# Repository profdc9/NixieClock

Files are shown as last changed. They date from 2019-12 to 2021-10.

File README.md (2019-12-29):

This a Nixie clock that uses IN-14 tubes and very generic, cheap, available through-hole parts so that it may be easily sourced in the future.  This material is copyrighted by Daniel Marks (KW4TI) and licensed under the Creative Commons License CC-BY-SA 4.0.  The software is licensed under the zlib license.  These are open source licenses that permit commercial use, modification and redistribution with attribution, and require licensees to assume all risk for using the copyrighted materials.

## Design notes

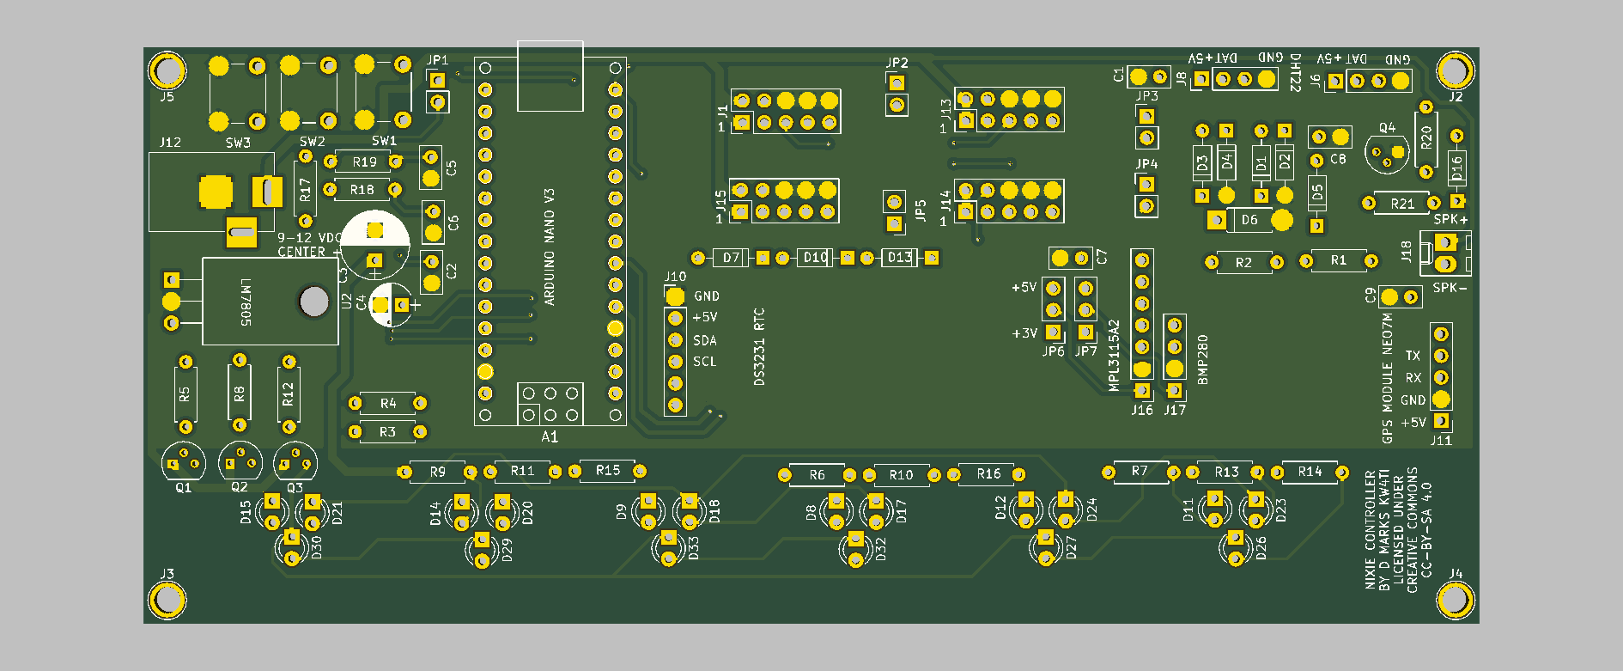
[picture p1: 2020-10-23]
NixieController/NixieController.png

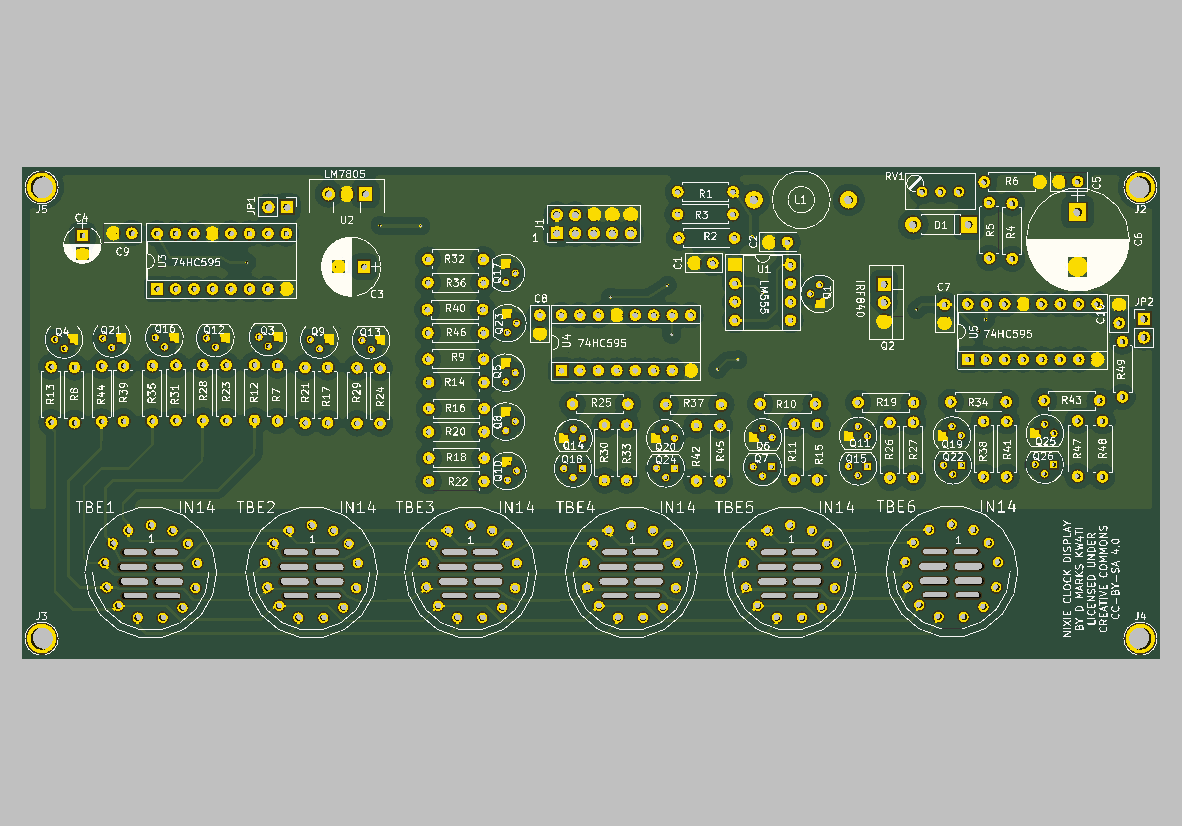
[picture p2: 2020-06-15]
NixieScanDisplay/NixieScanDisplay.png

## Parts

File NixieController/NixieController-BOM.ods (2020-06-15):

Source: | E:/Nixie/NixieController/NixieController.sch
Date: | 6/14/2020 10:06:16 PM
Tool: | Eeschema 4.0.7
Component Count: | 87
Ref | Value | Footprint | Datasheet | Manufacturer | Vendor
A1 | Arduino_Nano | Arduino Nano V3 (requires two pin header socket strips)
C1 | 100 nF | 100 nF 50 V ceramic disc capacitor
C3 | 10 uF | 10 uF 25 V electrolytic capacitor
C4 | 220 uF | 220 uF 10 V electrolytic capacitor
C7 | 100 nF | 100 nF 50 V ceramic disc capacitor
C8 | 100 nF | 100 nF 50 V ceramic disc capacitor
C9 | 100 nF | 100 nF 50 V ceramic disc capacitor
D1 | 1N4148 | 1N4148 DO-35 diode
D2 | 1N4148 | 1N4148 DO-35 diode
D3 | 1N4148 | 1N4148 DO-35 diode
D4 | 1N4148 | 1N4148 DO-35 diode
D5 | 1N4148 | 1N4148 DO-35 diode
D6 | 1N4733A | 1N4148 DO-35 diode
D7 | 1N4148 | 1N4148 DO-35 diode
D8 | LED | 3 mm Red Nondiffused Led
D9 | LED | 3 mm Red Nondiffused Led
D10 | 1N4148 | 1N4148 DO-35 diode
D11 | LED | 3 mm Red Nondiffused Led
D12 | LED | 3 mm Red Nondiffused Led
D13 | 1N4148 | 1N4148 DO-35 diode
D14 | LED | 3 mm Red Nondiffused Led
D15 | LED | 3 mm Red Nondiffused Led
D16 | 1N4148 | 1N4148 DO-35 diode
D17 | LED | 3 mm Green Nondiffused Led
D18 | LED | 3 mm Green Nondiffused Led
D20 | LED | 3 mm Green Nondiffused Led
D21 | LED | 3 mm Green Nondiffused Led
D23 | LED | 3 mm Green Nondiffused Led
D24 | LED | 3 mm Green Nondiffused Led
D26 | LED | 3 mm Blue Nondiffused Led
D27 | LED | 3 mm Blue Nondiffused Led
D29 | LED | 3 mm Blue Nondiffused Led
D30 | LED | 3 mm Blue Nondiffused Led
D32 | LED | 3 mm Blue Nondiffused Led
D33 | LED | 3 mm Blue Nondiffused Led
J1 | Conn_02x05_Odd_Even | 2 by 5 2.54 mm spacing pin headers
 |  | A 10 pin IDC ribbon cable with female connectors is needed
 |  | to connect controller and display PCBs
J6 | Conn_01x04 | 1 by 4 2.54 mm spacing pin header socket
 |  | DHT22 temperature and humidity module goes into socket J6
J8 | Conn_01x04 | 1 by 4 2.54 mm spacing pin header socket (optional)
J10 | Conn_01x06 | 1 by 6 2.54 mm spacing pin header socket (optional)
 |  | DS3231 RTC module goes into socket J10
J11 | Conn_01x05 | 1 by 5 2.54 mm spacing pin header socket (optional)
J12 | Barrel_Jack | Connectors:BARREL_JACK
J13 | Conn_02x05_Odd_Even | 2 by 5 2.54 mm spacing pin headers (optional)
J14 | Conn_02x05_Odd_Even | 2 by 5 2.54 mm spacing pin headers (optional)
J15 | Conn_02x05_Odd_Even | 2 by 5 2.54 mm spacing pin headers (optional)
J16 | Conn_01x07 | 1 by 7 2.54 mm spacing pin header socket (optional)
J17 | Conn_01x04 | 1 by 4 2.54 mm spacing pin header socket (optional)
J18 | Conn_01x02 | 1 by 2 JST2.54 pin connector for audio speaker
JP1 | Jumper_NC_Small | 1 by 2 2.54 mm spacing pin headers
JP2 | Jumper_NC_Small | 1 by 2 2.54 mm spacing pin headers
JP3 | Jumper_NC_Small | 1 by 2 2.54 mm spacing pin headers
JP4 | Jumper_NC_Small | 1 by 2 2.54 mm spacing pin headers
JP5 | Jumper_NC_Small | 1 by 2 2.54 mm spacing pin headers
JP6 | Jumper_NC_Dual | 1 by 3 2.54 mm spacing pin headers
JP7 | Jumper_NC_Dual | 1 by 3 2.54 mm spacing pin headers
Q1 | 2N2222A | 2N2222A TO-92 transistor
Q2 | 2N2222A | 2N2222A TO-92 transistor
Q3 | 2N2222A | 2N2222A TO-92 transistor
Q4 | 2N2222A | 2N2222A TO-92 transistor
R1 | 100R | 100 ohm ¼ watt axial resistor
R2 | 100R | 100 ohm ¼ watt axial resistor
R3 | 10k | 10k ohm ¼ watt axial resistor
R4 | 10k | 10k ohm ¼ watt axial resistor
R5 | 1k | 1k ohm ¼ watt axial resistor
R6 | 100R | 100 ohm ¼ watt axial resistor
R7 | 100R | 100 ohm ¼ watt axial resistor
R8 | 1k | 1k ohm ¼ watt axial resistor
R9 | 100R | 100 ohm ¼ watt axial resistor
R10 | 100R | 100 ohm ¼ watt axial resistor
R11 | 100R | 100 ohm ¼ watt axial resistor
R12 | 1k | 1k ohm ¼ watt axial resistor
R13 | 100R | 100 ohm ¼ watt axial resistor
R14 | 100R | 100 ohm ¼ watt axial resistor
R15 | 100R | 100 ohm ¼ watt axial resistor
R16 | 100R | 100 ohm ¼ watt axial resistor
R17 | 10k | 10k ohm ¼ watt axial resistor
R18 | 10k | 10k ohm ¼ watt axial resistor
R19 | 10k | 10k ohm ¼ watt axial resistor
R20 | 1k | 1k ohm ¼ watt axial resistor
R21 | 100R | 100 ohm ¼ watt axial resistor
SW1 | SW_Push | 6 mm PCB mount push button
SW2 | SW_Push | 6 mm PCB mount push button
SW3 | SW_Push | 6 mm PCB mount push button
U2 | L7805 | L7805 TO-220 voltage regulator

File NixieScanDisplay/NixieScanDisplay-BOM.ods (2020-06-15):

Source: | E:/Nixie/NixieScanDisplay/NixieScanDisplay.sch
Date: | 6/14/2020 10:06:40 PM
Tool: | Eeschema 4.0.7
Component Count: | 106
Ref | Value | Footprint | Datasheet | Manufacturer | Vendor
C1 | 2n2 | 2.2 nF 50 V ceramic disc capacitor
C2 | 100 nF | 100 nF 50 V ceramic disc capacitor
C3 | 10 uF | 10 uF 25 V electrolytic capacitor
C4 | 220 uF | 220 uF 10 V electrolytic capacitor
C5 | 100 pF | 100 pF 50 V ceramic disc capacitor
C6 | 4u7 | 4.7 uF 400 V electrolytic capacitor
C7 | 100 nF | 100 nF 50 V ceramic disc capacitor
C8 | 100 nF | 100 nF 50 V ceramic disc capacitor
C9 | 100 nF | 100 nF 50 V ceramic disc capacitor
C10 | 100 nF | 100 nF 50 V ceramic disc capacitor
D1 | UF4007 | UF4007 DO-41 diode
J1 | Conn_02x05_Odd_Even | 2 by 5 2.54 mm spacing pin headers
 |  | A 10 pin IDC ribbon cable with female connectors is needed
 |  | to connect controller and display PCBs
JP1 | Jumper_NC_Small | 1 by 2 2.54 mm spacing pin headers
JP2 | Jumper_NC_Small | 1 by 2 2.54 mm spacing pin headers
L1 | 100 uH | 100 uH ferrite inductor (Can use 150 uH VLU0810-151KF lcsc.com C401476)
Q1 | 2N2222A | 2N2222A TO-92 transistor
Q2 | IRF840 | IRF840N TO-220 MOSFET ( lcsc.com C358409 )
Q3 | MPSA42 | MPSA42 high voltage NPN (lcsc.com C118557 )
Q4 | MPSA42 | MPSA42 high voltage NPN (lcsc.com C118557 )
Q5 | MPSA42 | MPSA42 high voltage NPN (lcsc.com C118557 )
Q6 | MPSA42 | MPSA42 high voltage NPN (lcsc.com C118557 )
Q7 | MPSA92 | MPSA92 high voltage PNP (lcsc.com C118558 )
Q8 | MPSA42 | MPSA42 high voltage NPN (lcsc.com C118557 )
Q9 | MPSA42 | MPSA42 high voltage NPN (lcsc.com C118557 )
Q10 | MPSA42 | MPSA42 high voltage NPN (lcsc.com C118557 )
Q11 | MPSA42 | MPSA42 high voltage NPN (lcsc.com C118557 )
Q12 | MPSA42 | MPSA42 high voltage NPN (lcsc.com C118557 )
Q13 | MPSA42 | MPSA42 high voltage NPN (lcsc.com C118557 )
Q14 | MPSA42 | MPSA42 high voltage NPN (lcsc.com C118557 )
Q15 | MPSA92 | MPSA92 high voltage PNP (lcsc.com C118558 )
Q16 | MPSA42 | MPSA42 high voltage NPN (lcsc.com C118557 )
Q17 | MPSA42 | MPSA42 high voltage NPN (lcsc.com C118557 )
Q18 | MPSA92 | MPSA92 high voltage PNP (lcsc.com C118558 )
Q19 | MPSA42 | MPSA42 high voltage NPN (lcsc.com C118557 )
Q20 | MPSA42 | MPSA42 high voltage NPN (lcsc.com C118557 )
Q21 | MPSA42 | MPSA42 high voltage NPN (lcsc.com C118557 )
Q22 | MPSA92 | MPSA92 high voltage PNP (lcsc.com C118558 )
Q23 | MPSA42 | MPSA42 high voltage NPN (lcsc.com C118557 )
Q24 | MPSA92 | MPSA92 high voltage PNP (lcsc.com C118558 )
Q25 | MPSA42 | MPSA42 high voltage NPN (lcsc.com C118557 )
Q26 | MPSA92 | MPSA92 high voltage PNP (lcsc.com C118558 )
R1 | 56k | 56k ¼ watt axial resistor
R2 | 1k | 1k ¼ watt axial resistor
R3 | 10k | 10k ¼ watt axial resistor
R4 | 2k2 | 2.2k ¼ watt axial reistor
R5 | 220k | 220k ¼ watt axial resistor
R6 | 470R | 470 ohm ¼ watt axial resistor
R7 | 10k | 10k ¼ watt axial resistor
R8 | 10k | 10k ¼ watt axial resistor
R9 | 10k | 10k ¼ watt axial resistor
R10 | 10k | 10k ¼ watt axial resistor
R11 | 1M | 1 M ¼ watt axial resistor
R12 | 22k | 22k ¼ watt axial resistor
R13 | 10k | 10k ¼ watt axial resistor
R14 | 10k | 10k ¼ watt axial resistor
R15 | 10M | 10M ¼ watt axial resistor
R16 | 10k | 10k ¼ watt axial resistor
R17 | 10k | 10k ¼ watt axial resistor
R18 | 10k | 10k ¼ watt axial resistor
R19 | 10k | 10k ¼ watt axial resistor
R20 | 10k | 10k ¼ watt axial resistor
R21 | 10k | 10k ¼ watt axial resistor
R22 | 22k | 22k ¼ watt axial resistor
R23 | 10k | 10k ¼ watt axial resistor
R24 | 10k | 10k ¼ watt axial resistor
R25 | 10k | 10k ¼ watt axial resistor
R26 | 1M | 1 M ¼ watt axial resistor
R27 | 10M | 10M ¼ watt axial resistor
R28 | 10k | 10k ¼ watt axial resistor
R29 | 10k | 10k ¼ watt axial resistor
R30 | 1M | 1 M ¼ watt axial resistor
R31 | 10k | 10k ¼ watt axial resistor
R32 | 10k | 10k ¼ watt axial resistor
R33 | 10M | 10M ¼ watt axial resistor
R34 | 10k | 10k ¼ watt axial resistor
R35 | 10k | 10k ¼ watt axial resistor
R36 | 10k | 10k ¼ watt axial resistor
R37 | 10k | 10k ¼ watt axial resistor
R38 | 1M | 1 M ¼ watt axial resistor
R39 | 10k | 10k ¼ watt axial resistor
R40 | 10k | 10k ¼ watt axial resistor
R41 | 10M | 10M ¼ watt axial resistor
R42 | 1M | 1 M ¼ watt axial resistor
R43 | 10k | 10k ¼ watt axial resistor
R44 | 10k | 10k ¼ watt axial resistor
R45 | 10M | 10M ¼ watt axial resistor
R46 | 10k | 10k ¼ watt axial resistor
R47 | 1M | 1 M ¼ watt axial resistor
R48 | 10M | 10M ¼ watt axial resistor
R49 | 10k | 10k ¼ watt axial resistor
RV1 | 1k | 1k Bourns-type 3296W potentiometer (lcsc.com C118949 )
TBE1 | IN14 | IN-14 nixie tube
TBE2 | IN14 | IN-14 nixie tube
TBE3 | IN14 | IN-14 nixie tube
TBE4 | IN14 | IN-14 nixie tube
TBE5 | IN14 | IN-14 nixie tube
TBE6 | IN14 | IN-14 nixie tube
U1 | NE555 | NE555 DIP-8 IC
U2 | L7805 | omit
U3 | 74HC595 | 74HC595 DIP-16 IC
U4 | 74HC595 | 74HC595 DIP-16 IC
U5 | 74HC595 | 74HC595 DIP-16 IC

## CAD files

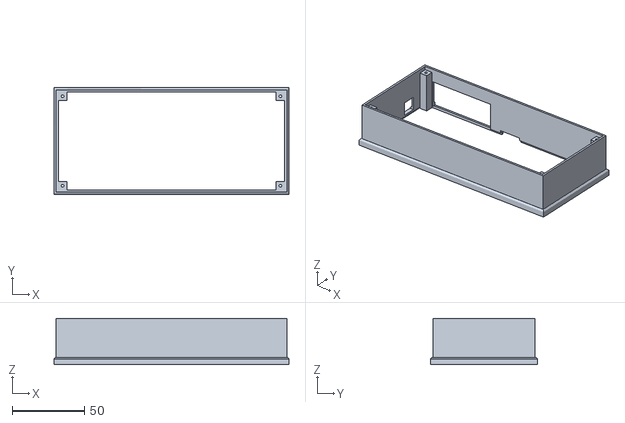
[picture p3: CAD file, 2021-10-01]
CAD/clock-enclosure-top-wall.stl
163.0 x 74.0 x 32.0

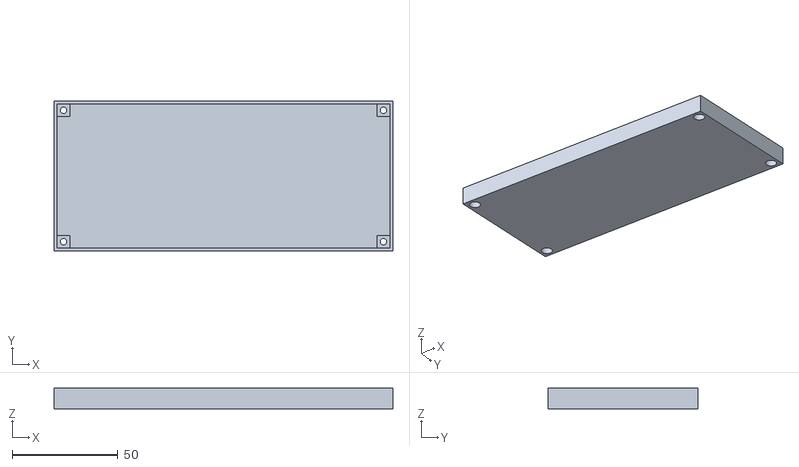
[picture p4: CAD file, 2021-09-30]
CAD/clock-enclosure-case-bottom.stl
160.0 x 71.0 x 9.70

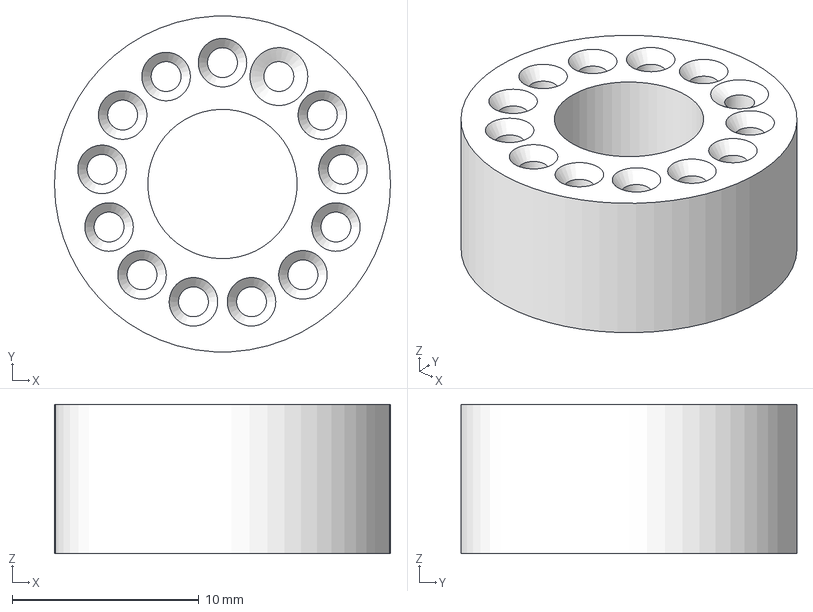
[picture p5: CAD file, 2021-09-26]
CAD/nixie-tube-lead-aligner.FCStd
18.0 x 18.0 x 8.00 mm

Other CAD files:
CAD/clock-enclosure.FCStd
CAD/alignment-tool.stl

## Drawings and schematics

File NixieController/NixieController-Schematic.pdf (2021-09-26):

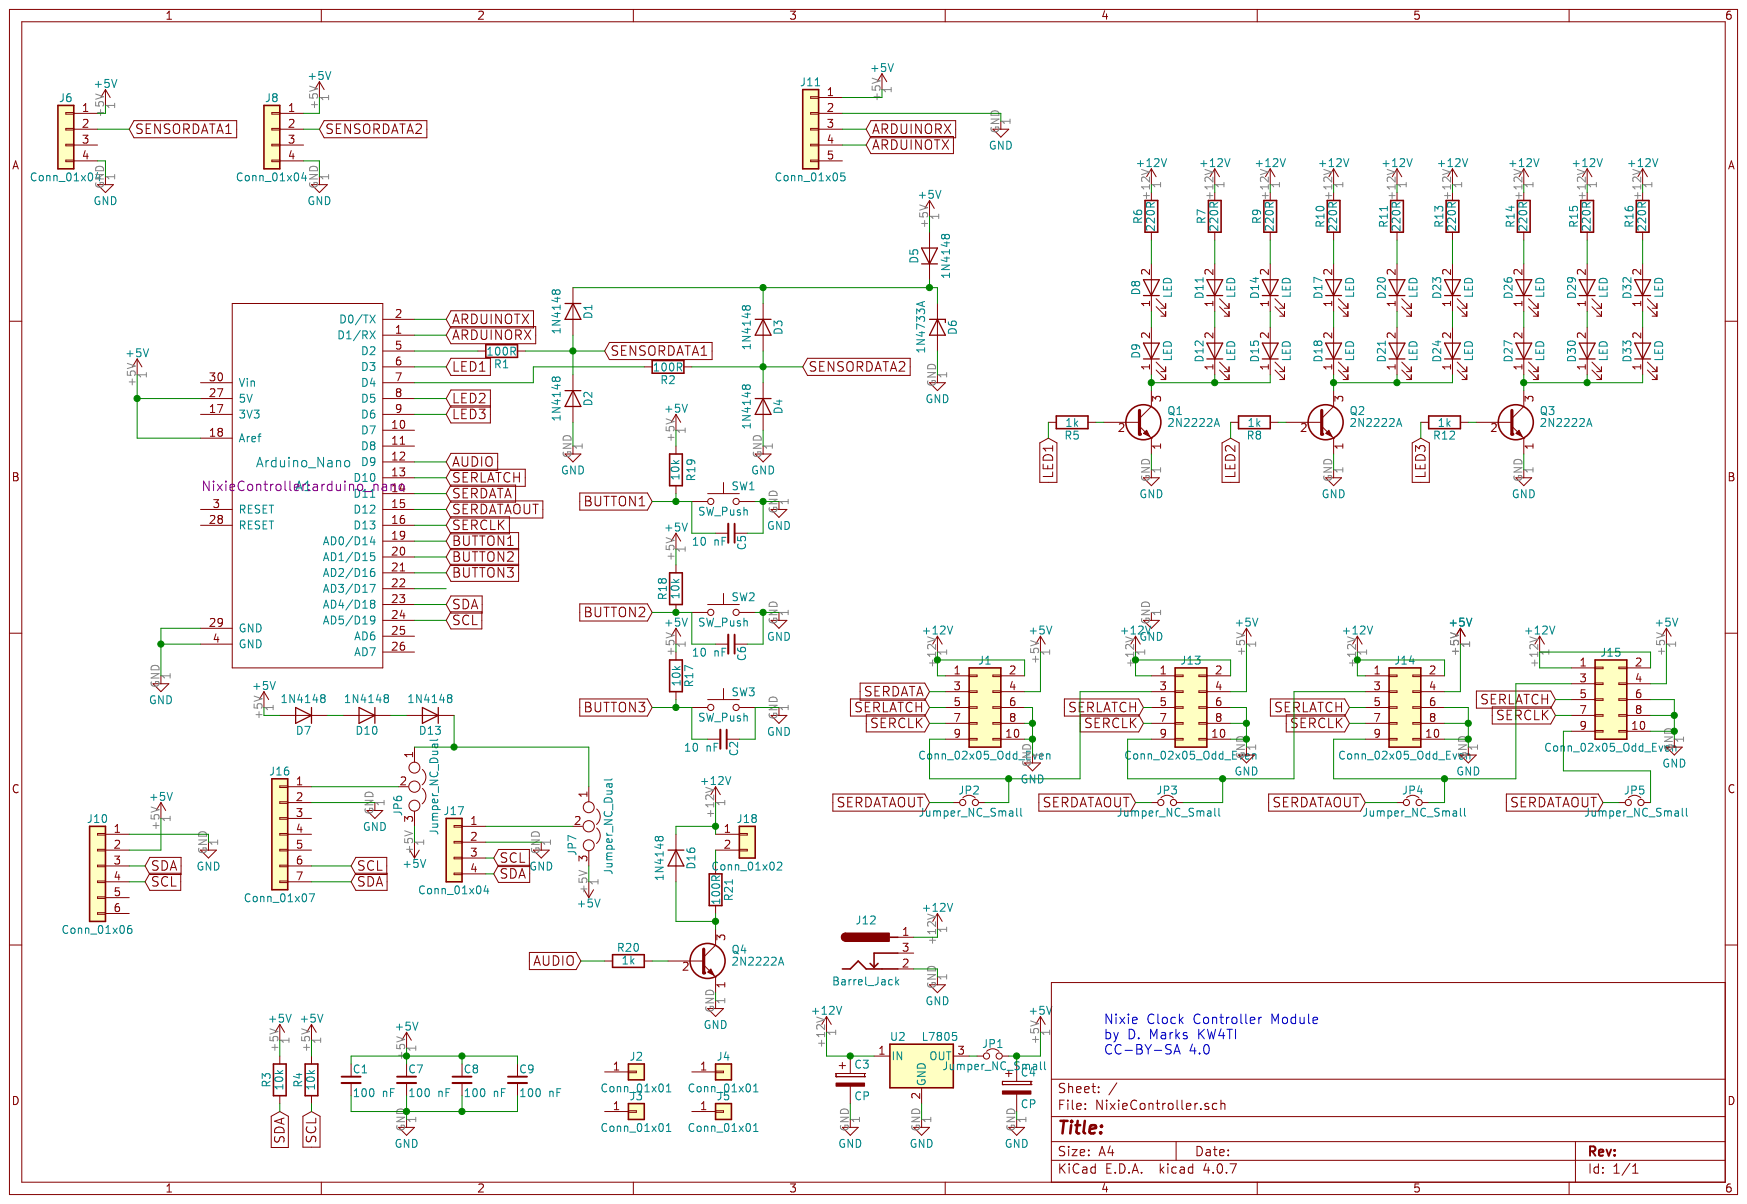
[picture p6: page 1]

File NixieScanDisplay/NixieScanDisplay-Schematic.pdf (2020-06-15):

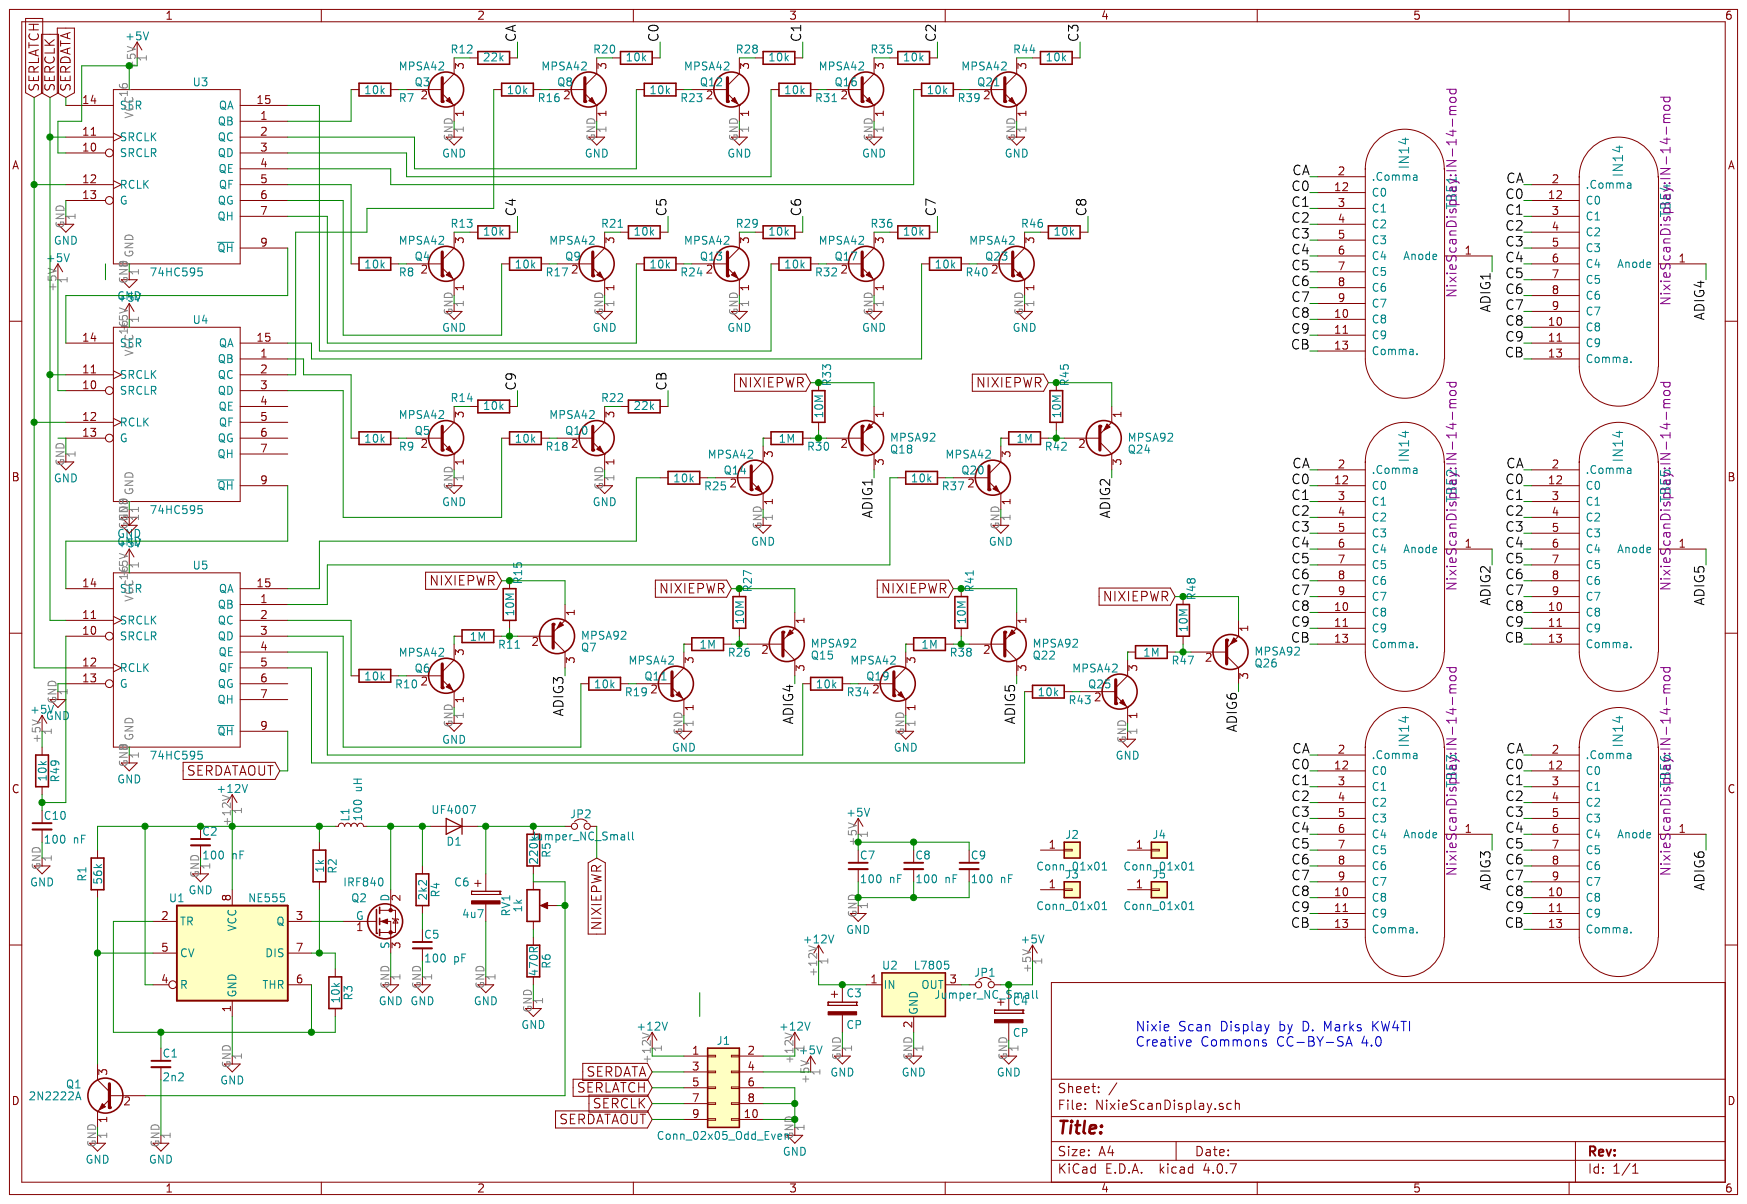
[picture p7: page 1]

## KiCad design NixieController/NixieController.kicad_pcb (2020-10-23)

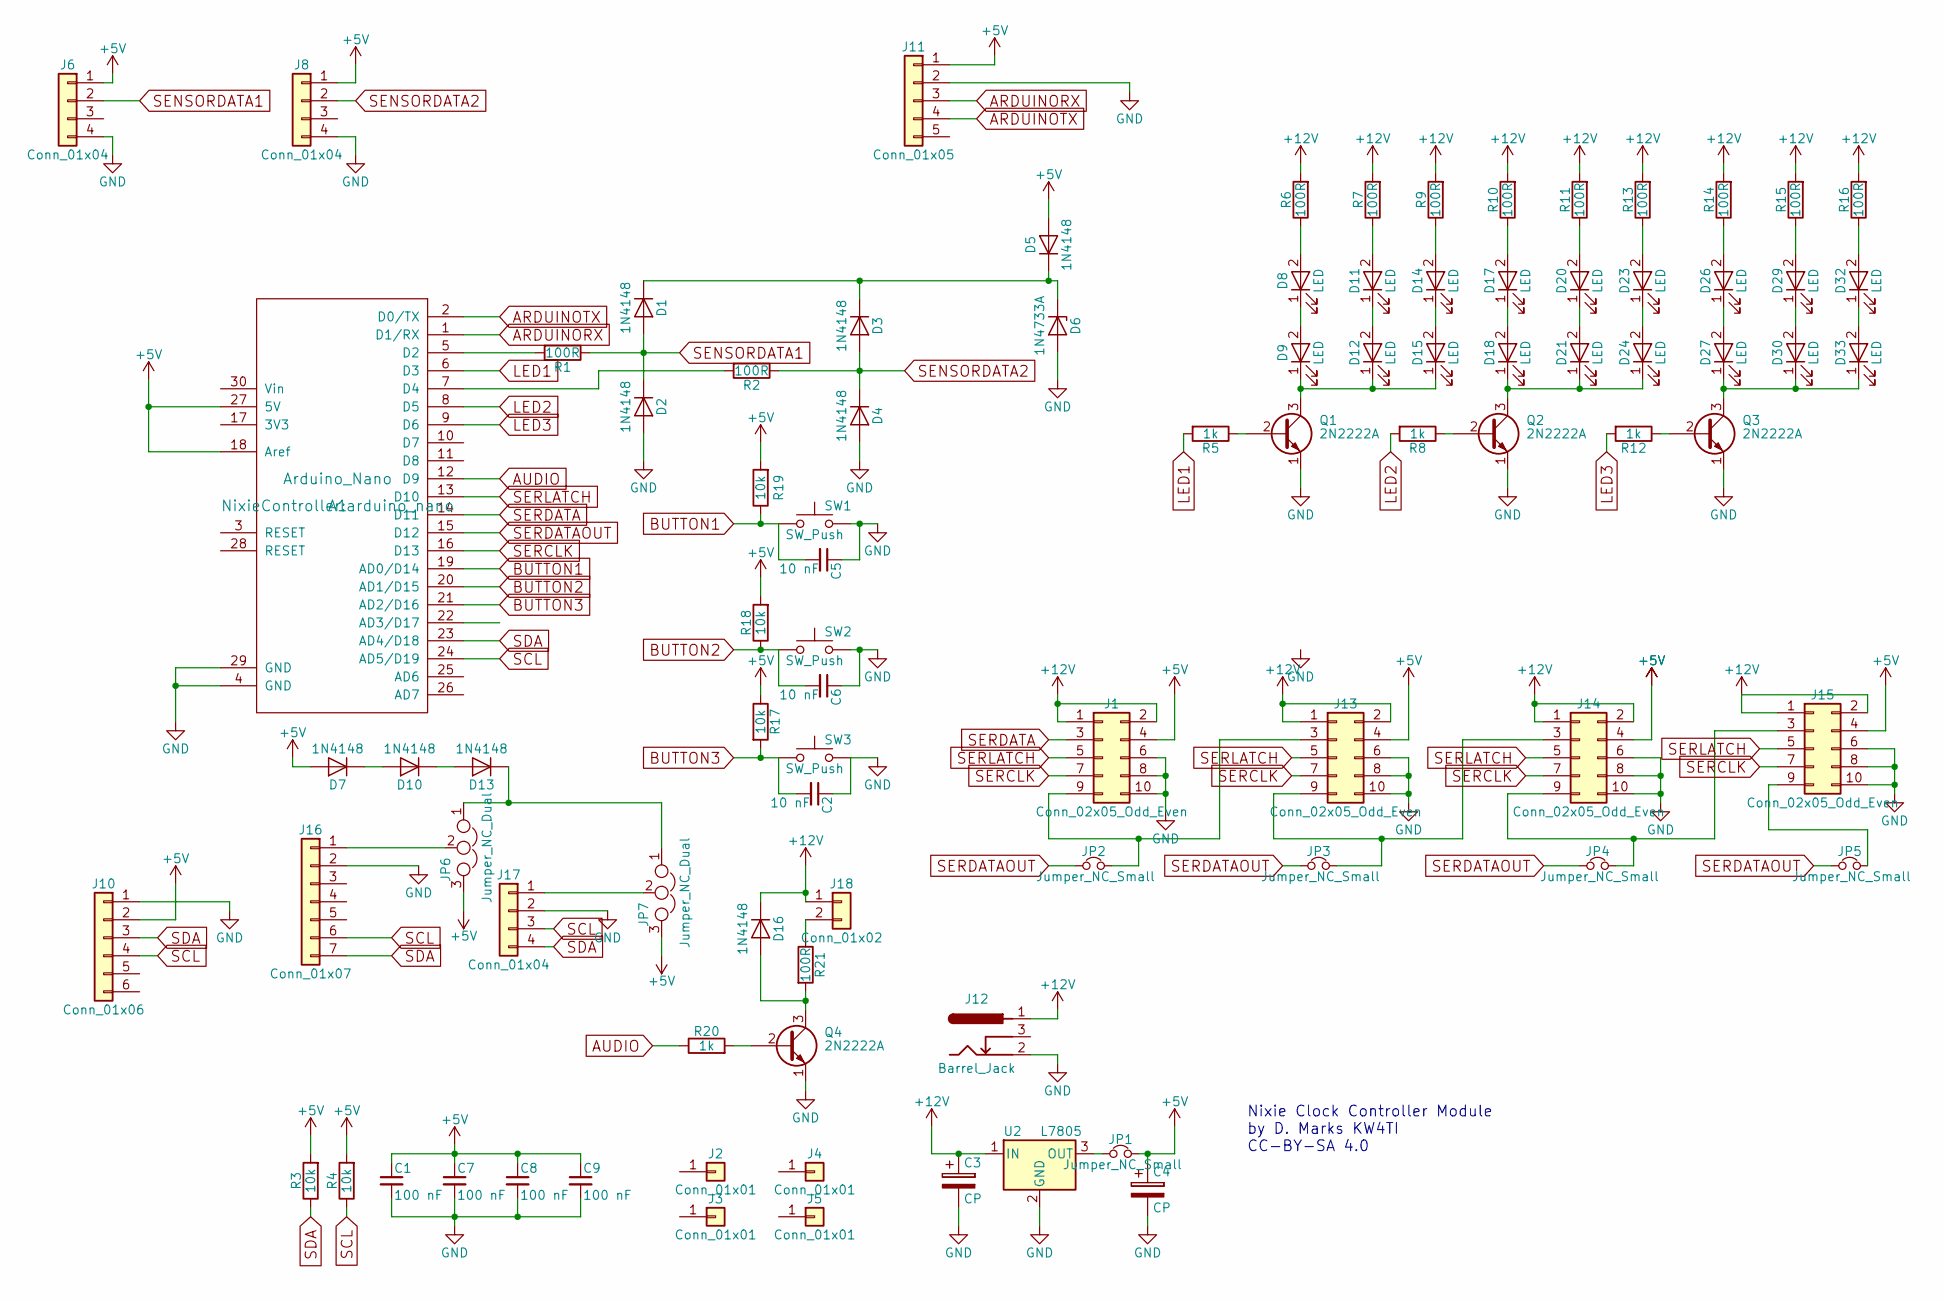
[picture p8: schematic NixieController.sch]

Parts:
A1: Arduino_Nano; arduino_nano
C1, C7, C8, C9: 100 nF; C_Disc_D5.0mm_W2.5mm_P2.50mm
C2, C5, C6: 10 nF; C_Disc_D5.0mm_W2.5mm_P2.50mm
C3: CP; CP_Radial_D8.0mm_P3.50mm
C4: CP; CP_Radial_D5.0mm_P2.50mm
D1, D2, D3, D4, D5, D7, D10, D13, D16: 1N4148; D_DO-35_SOD27_P7.62mm_Horizontal
D6: 1N4733A; D_DO-41_SOD81_P7.62mm_Horizontal
D8, D9, D11, D12, D14, D15, D17, D18, D20, D21, D23, D24, D26, D27, D29, D30, D32, D33: LED; LED_D3.0mm
J1, J13, J14, J15: Conn_02x05_Odd_Even; Pin_Header_Straight_2x05_Pitch2.54mm
J2, J3, J4, J5: Conn_01x01; 1pin
J6, J8, J17: Conn_01x04; Pin_Header_Straight_1x04_Pitch2.54mm
J10: Conn_01x06; Pin_Header_Straight_1x06_Pitch2.54mm
J11: Conn_01x05; Pin_Header_Straight_1x05_Pitch2.54mm
J12: Barrel_Jack; BARREL_JACK
J16: Conn_01x07; Pin_Header_Straight_1x07_Pitch2.54mm
J18: Conn_01x02; Molex_KK-6410-02_02x2.54mm_Straight
JP1, JP2, JP3, JP4, JP5: Jumper_NC_Small; Pin_Header_Straight_1x02_Pitch2.54mm
JP6, JP7: Jumper_NC_Dual; Pin_Header_Straight_1x03_Pitch2.54mm
Q1, Q2, Q3, Q4: 2N2222A; TO-92_Molded_Narrow
R1, R2, R6, R7, R9, R10, R11, R13, R14, R15, R16, R21: 100R; R_Axial_DIN0207_L6.3mm_D2.5mm_P7.62mm_Horizontal
R3, R4, R17, R18, R19: 10k; R_Axial_DIN0207_L6.3mm_D2.5mm_P7.62mm_Horizontal
R5, R8, R12, R20: 1k; R_Axial_DIN0207_L6.3mm_D2.5mm_P7.62mm_Horizontal
SW1, SW2, SW3: SW_Push; SW_PUSH_6mm
U2: L7805; TO-220-3_Horizontal

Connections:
+5V: A1.18 (Aref), A1.27 (5V), C1.1, C4.1, C7.1, C8.1, C9.1, D5.2 (A), D7.2 (A), J1.4, J6.1, J8.1, J10.2, J11.1, J13.4, J14.4, J15.4, JP1.2, JP6.3, JP7.3, R3.2, R4.2, R17.1, R18.2, R19.2
+12V: C3.1, D16.1 (K), J1.1, J1.2, J12.1, J13.1, J13.2, J14.1, J14.2, J15.1, J15.2, J18.1, R6.2, R7.2, R9.2, R10.2, R11.2, R13.2, R14.2, R15.2, R16.2, U2.1 (IN)
ARDUINORX: A1.1 (D1/RX), J11.3
ARDUINOTX: A1.2 (D0/TX), J11.4
AUDIO: A1.12 (D9), R20.1
BUTTON1: A1.19 (AD0/D14), C5.2, R19.1, SW1.1
BUTTON2: A1.20 (AD1/D15), C6.2, R18.1, SW2.1
BUTTON3: A1.21 (AD2/D16), C2.2, R17.2, SW3.1
GND: A1.4 (GND), A1.29 (GND), C1.2, C2.1, C3.2, C4.2, C5.1, C6.1, C7.2, C8.2, C9.2, D2.2 (A), D4.2 (A), D6.2 (A), J1.6, J1.8, J1.10, J6.4, J8.4, J10.1, J11.2, J12.2, J13.6, J13.8, J13.10, J14.6, J14.8, J14.10, J15.6, J15.8, J15.10, J16.2, J17.2, Q1.1 (E), Q2.1 (E), Q3.1 (E), Q4.1 (E), SW1.2, SW2.2, SW3.2, U2.2 (GND)
LED1: A1.6 (D3), R5.2
LED2: A1.8 (D5), R8.2
LED3: A1.9 (D6), R12.2
unnamed: A1.5 (D2), R1.2
unnamed: A1.7 (D4), R2.2
unnamed: D1.1 (K), D3.1 (K), D5.1 (K), D6.1 (K)
unnamed: D8.1 (K), D9.2 (A)
unnamed: D8.2 (A), R6.1
unnamed: D10.1 (K), D13.2 (A)
unnamed: D7.1 (K), D10.2 (A)
unnamed: D11.1 (K), D12.2 (A)
unnamed: D11.2 (A), R7.1
unnamed: D9.1 (K), D12.1 (K), D15.1 (K), Q1.3 (C)
unnamed: D13.1 (K), JP6.1, JP7.1
unnamed: D14.1 (K), D15.2 (A)
unnamed: D14.2 (A), R9.1
unnamed: D16.2 (A), Q4.3 (C), R21.2
unnamed: D17.1 (K), D18.2 (A)
unnamed: D17.2 (A), R10.1
unnamed: D18.1 (K), D21.1 (K), D24.1 (K), Q2.3 (C)
unnamed: D20.1 (K), D21.2 (A)
unnamed: D20.2 (A), R11.1
unnamed: D23.1 (K), D24.2 (A)
unnamed: D23.2 (A), R13.1
unnamed: D26.1 (K), D27.2 (A)
unnamed: D26.2 (A), R14.1
unnamed: D27.1 (K), D30.1 (K), D33.1 (K), Q3.3 (C)
unnamed: D29.1 (K), D30.2 (A)
unnamed: D29.2 (A), R15.1
unnamed: D32.1 (K), D33.2 (A)
unnamed: D32.2 (A), R16.1
unnamed: J1.9, J13.3, JP2.2
unnamed: J13.9, J14.3, JP3.2
unnamed: J14.9, J15.3, JP4.2
unnamed: J15.9, JP5.2
unnamed: J16.1, JP6.2
unnamed: J17.1, JP7.2
unnamed: J18.2, R21.1
unnamed: JP1.1, U2.3 (OUT)
unnamed: Q1.2 (B), R5.1
unnamed: Q2.2 (B), R8.1
unnamed: Q3.2 (B), R12.1
unnamed: Q4.2 (B), R20.2
SCL: A1.24 (AD5/D19), J10.4, J16.6, J17.3, R4.1
SDA: A1.23 (AD4/D18), J10.3, J16.7, J17.4, R3.1
SENSORDATA1: D1.2 (A), D2.1 (K), J6.2, R1.1
SENSORDATA2: D3.2 (A), D4.1 (K), J8.2, R2.1
SERCLK: A1.16 (D13), J1.7, J13.7, J14.7, J15.7
SERDATA: A1.14 (D11), J1.3
SERDATAOUT: A1.15 (D12), JP2.1, JP3.1, JP4.1, JP5.1
SERLATCH: A1.13 (D10), J1.5, J13.5, J14.5, J15.5

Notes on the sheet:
Nixie Clock Controller Module by D. Marks KW4TI CC-BY-SA 4.0

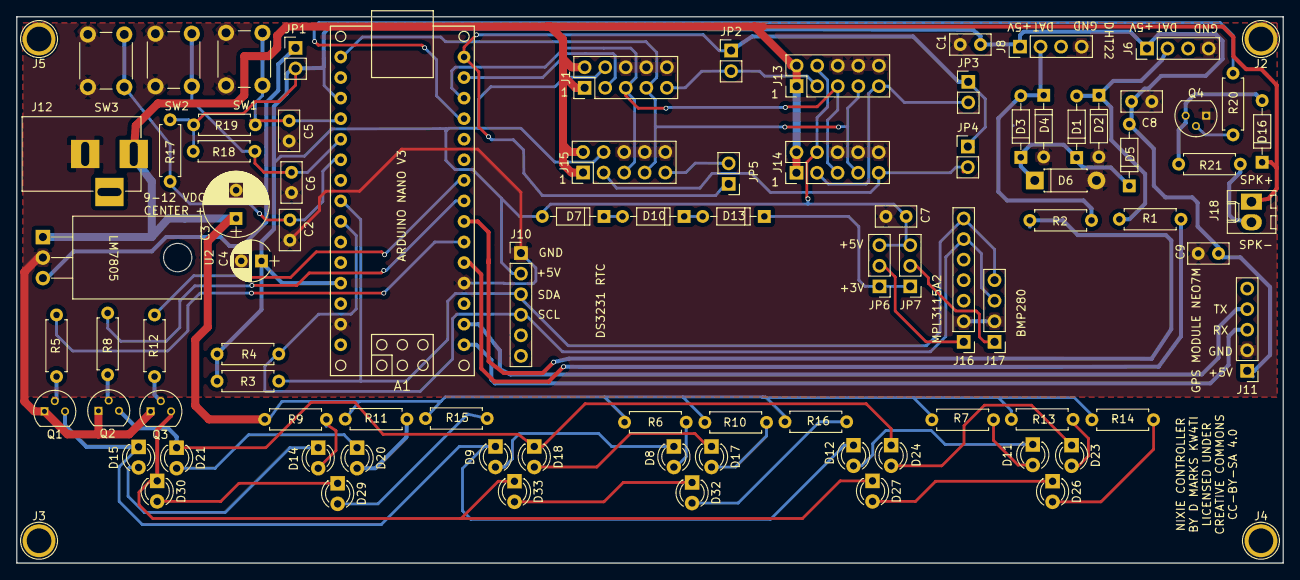
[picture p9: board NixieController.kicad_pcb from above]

Board: 2 copper layers, 156.5 x 67.5 mm, 90 parts (0 on the bottom side), 60 nets.

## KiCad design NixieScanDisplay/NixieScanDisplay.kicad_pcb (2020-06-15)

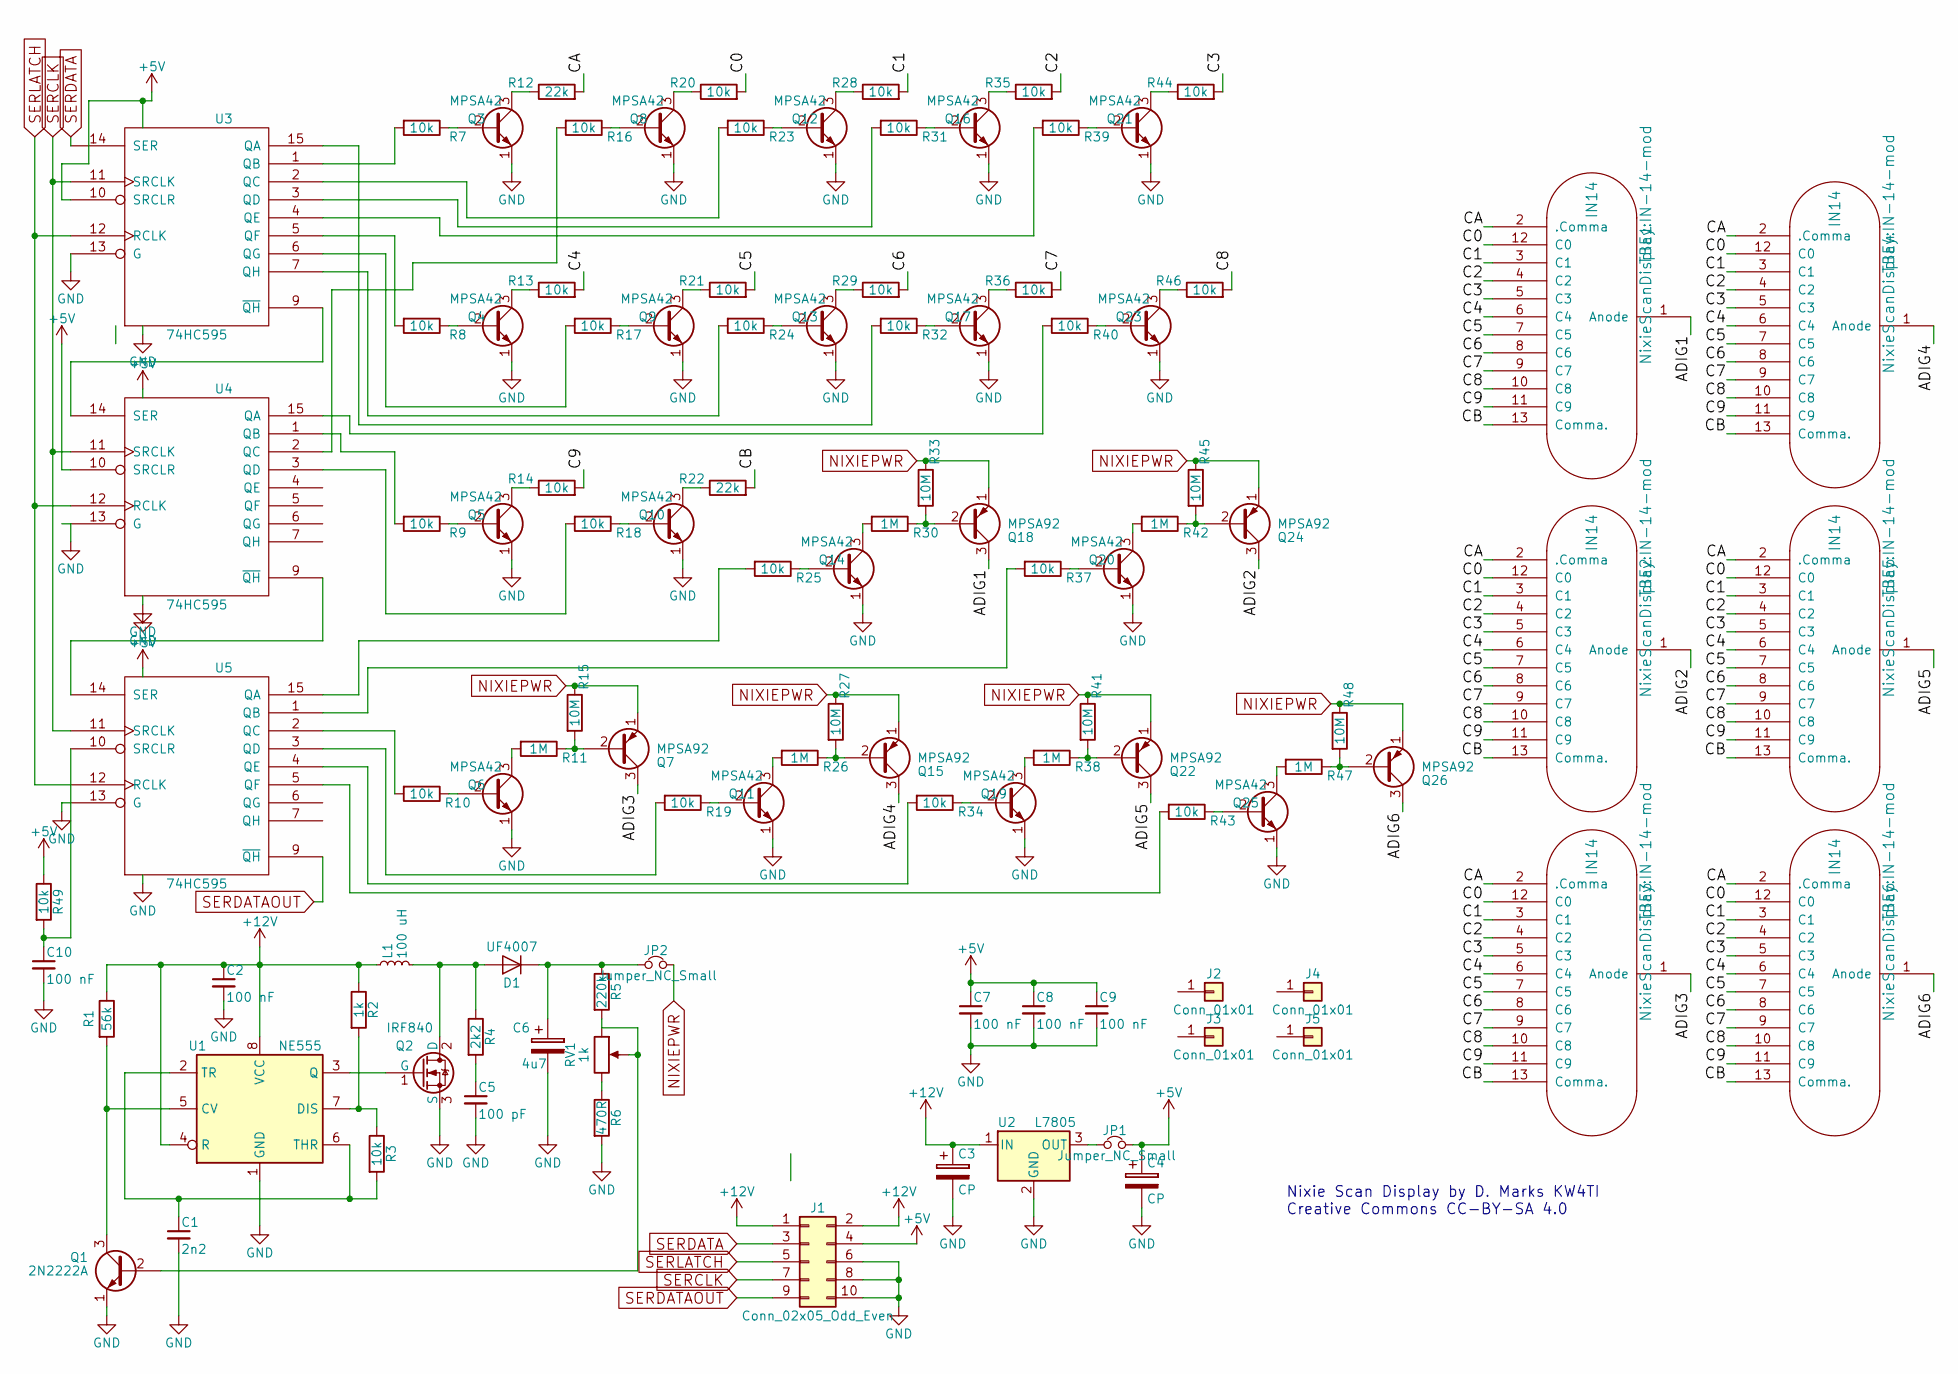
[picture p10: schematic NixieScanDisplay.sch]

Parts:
C1: 2n2; C_Disc_D5.0mm_W2.5mm_P2.50mm
C2, C7, C8, C9, C10: 100 nF; C_Disc_D5.0mm_W2.5mm_P2.50mm
C3: CP; CP_Radial_D8.0mm_P3.50mm
C4: CP; CP_Radial_D5.0mm_P2.50mm
C5: 100 pF; C_Disc_D5.0mm_W2.5mm_P2.50mm
C6: 4u7; CP_Radial_D14.0mm_P7.50mm
D1: UF4007; D_DO-41_SOD81_P7.62mm_Horizontal
J1: Conn_02x05_Odd_Even; Pin_Header_Straight_2x05_Pitch2.54mm
J2, J3, J4, J5: Conn_01x01; 1pin
JP1, JP2: Jumper_NC_Small; Pin_Header_Straight_1x02_Pitch2.54mm
L1: 100 uH; L_Toroid_Horizontal_D7.8mm_P13.00mm_Diameter9-5mm_Amidon-T30
Q1: 2N2222A; TO-92_Molded_Narrow
Q2: IRF840; TO-220-3_Vertical
Q3, Q4, Q5, Q6, Q8, Q9, Q10, Q11, Q12, Q13, Q14, Q16, Q17, Q19, Q20, Q21, Q23, Q25: MPSA42; TO-92_Molded_Narrow
Q7, Q15, Q18, Q22, Q24, Q26: MPSA92; TO-92_Molded_Narrow
R1: 56k; R_Axial_DIN0207_L6.3mm_D2.5mm_P7.62mm_Horizontal
R2: 1k; R_Axial_DIN0207_L6.3mm_D2.5mm_P7.62mm_Horizontal
R3, R7, R8, R9, R10, R13, R14, R16, R17, R18, R19, R20, R21, R23, R24, R25, R28, R29, R31, R32, R34, R35, R36, R37, R39, R40, R43, R44, R46, R49: 10k; R_Axial_DIN0207_L6.3mm_D2.5mm_P7.62mm_Horizontal
R4: 2k2; R_Axial_DIN0207_L6.3mm_D2.5mm_P7.62mm_Horizontal
R5: 220k; R_Axial_DIN0207_L6.3mm_D2.5mm_P7.62mm_Horizontal
R6: 470R; R_Axial_DIN0207_L6.3mm_D2.5mm_P7.62mm_Horizontal
R11, R26, R30, R38, R42, R47: 1M; R_Axial_DIN0207_L6.3mm_D2.5mm_P7.62mm_Horizontal
R12, R22: 22k; R_Axial_DIN0207_L6.3mm_D2.5mm_P7.62mm_Horizontal
R15, R27, R33, R41, R45, R48: 10M; R_Axial_DIN0207_L6.3mm_D2.5mm_P7.62mm_Horizontal
RV1: 1k; Potentiometer_Trimmer_Bourns_3296W
TBE1, TBE2, TBE3, TBE4, TBE5, TBE6: IN14; IN-14-mod
U1: NE555; DIP-8_W7.62mm_Socket
U2: L7805; TO-220-3_Vertical
U3, U4, U5: 74HC595; DIP-16_W7.62mm_Socket

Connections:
+5V: C4.1, C7.1, C8.1, C9.1, J1.4, JP1.2, R49.1, U3.10 (SRCLR), U3.16 (VCC), U4.10 (SRCLR), U4.16 (VCC), U5.16 (VCC)
+12V: C2.1, C3.1, J1.1, J1.2, L1.1, R1.1, R2.1, U1.4 (R), U1.8 (VCC), U2.1 (IN)
/ADIG1: Q18.3 (C), TBE1.1 (Anode)
/ADIG2: Q24.3 (C), TBE2.1 (Anode)
/ADIG3: Q7.3 (C), TBE3.1 (Anode)
/ADIG4: Q15.3 (C), TBE4.1 (Anode)
/ADIG5: Q22.3 (C), TBE5.1 (Anode)
/ADIG6: Q26.3 (C), TBE6.1 (Anode)
/C0: R20.2, TBE1.12 (C0), TBE2.12 (C0), TBE3.12 (C0), TBE4.12 (C0), TBE5.12 (C0), TBE6.12 (C0)
/C1: R28.2, TBE1.3 (C1), TBE2.3 (C1), TBE3.3 (C1), TBE4.3 (C1), TBE5.3 (C1), TBE6.3 (C1)
/C2: R35.2, TBE1.4 (C2), TBE2.4 (C2), TBE3.4 (C2), TBE4.4 (C2), TBE5.4 (C2), TBE6.4 (C2)
/C3: R44.2, TBE1.5 (C3), TBE2.5 (C3), TBE3.5 (C3), TBE4.5 (C3), TBE5.5 (C3), TBE6.5 (C3)
/C4: R13.2, TBE1.6 (C4), TBE2.6 (C4), TBE3.6 (C4), TBE4.6 (C4), TBE5.6 (C4), TBE6.6 (C4)
/C5: R21.2, TBE1.7 (C5), TBE2.7 (C5), TBE3.7 (C5), TBE4.7 (C5), TBE5.7 (C5), TBE6.7 (C5)
/C6: R29.2, TBE1.8 (C6), TBE2.8 (C6), TBE3.8 (C6), TBE4.8 (C6), TBE5.8 (C6), TBE6.8 (C6)
/C7: R36.2, TBE1.9 (C7), TBE2.9 (C7), TBE3.9 (C7), TBE4.9 (C7), TBE5.9 (C7), TBE6.9 (C7)
/C8: R46.2, TBE1.10 (C8), TBE2.10 (C8), TBE3.10 (C8), TBE4.10 (C8), TBE5.10 (C8), TBE6.10 (C8)
/C9: R14.2, TBE1.11 (C9), TBE2.11 (C9), TBE3.11 (C9), TBE4.11 (C9), TBE5.11 (C9), TBE6.11 (C9)
/CA: R12.2, TBE1.2 (.Comma), TBE2.2 (.Comma), TBE3.2 (.Comma), TBE4.2 (.Comma), TBE5.2 (.Comma), TBE6.2 (.Comma)
/CB: R22.2, TBE1.13 (Comma.), TBE2.13 (Comma.), TBE3.13 (Comma.), TBE4.13 (Comma.), TBE5.13 (Comma.), TBE6.13 (Comma.)
GND: C1.2, C2.2, C3.2, C4.2, C5.2, C6.2, C7.2, C8.2, C9.2, C10.2, J1.6, J1.8, J1.10, Q1.1 (E), Q2.3 (S), Q3.1 (E), Q4.1 (E), Q5.1 (E), Q6.1 (E), Q8.1 (E), Q9.1 (E), Q10.1 (E), Q11.1 (E), Q12.1 (E), Q13.1 (E), Q14.1 (E), Q16.1 (E), Q17.1 (E), Q19.1 (E), Q20.1 (E), Q21.1 (E), Q23.1 (E), Q25.1 (E), R6.2, U1.1 (GND), U2.2 (GND), U3.8 (GND), U3.13 (G), U4.8 (GND), U4.13 (G), U5.8 (GND), U5.13 (G)
NIXIEPWR: JP2.2, Q7.1 (E), Q15.1 (E), Q18.1 (E), Q22.1 (E), Q24.1 (E), Q26.1 (E), R15.1, R27.1, R33.1, R41.1, R45.1, R48.1
unnamed: C1.1, R3.2, U1.2 (TR), U1.6 (THR)
unnamed: C5.1, R4.2
unnamed: C6.1, D1.1 (K), JP2.1, R5.1
unnamed: C10.1, R49.2, U5.10 (SRCLR)
unnamed: D1.2 (A), L1.2, Q2.2 (D), R4.1
unnamed: JP1.1, U2.3 (OUT)
unnamed: Q1.2 (B), R5.2, RV1.1, RV1.2
unnamed: Q1.3 (C), R1.2, U1.5 (CV)
unnamed: Q2.1 (G), U1.3 (Q)
unnamed: Q3.2 (B), R7.1
unnamed: Q3.3 (C), R12.1
unnamed: Q4.2 (B), R8.1
unnamed: Q4.3 (C), R13.1
unnamed: Q5.2 (B), R9.1
unnamed: Q5.3 (C), R14.1
unnamed: Q6.2 (B), R10.1
unnamed: Q6.3 (C), R11.2
unnamed: Q7.2 (B), R11.1, R15.2
unnamed: Q8.2 (B), R16.1
unnamed: Q8.3 (C), R20.1
unnamed: Q9.2 (B), R17.1
unnamed: Q9.3 (C), R21.1
unnamed: Q10.2 (B), R18.1
unnamed: Q10.3 (C), R22.1
unnamed: Q11.2 (B), R19.1
unnamed: Q11.3 (C), R26.2
unnamed: Q12.2 (B), R23.1
unnamed: Q12.3 (C), R28.1
unnamed: Q13.2 (B), R24.1
unnamed: Q13.3 (C), R29.1
unnamed: Q14.2 (B), R25.1
unnamed: Q14.3 (C), R30.2
unnamed: Q15.2 (B), R26.1, R27.2
unnamed: Q16.2 (B), R31.1
unnamed: Q16.3 (C), R35.1
unnamed: Q17.2 (B), R32.1
unnamed: Q17.3 (C), R36.1
unnamed: Q18.2 (B), R30.1, R33.2
unnamed: Q19.2 (B), R34.1
unnamed: Q19.3 (C), R38.2
unnamed: Q20.2 (B), R37.1
unnamed: Q20.3 (C), R42.2
unnamed: Q21.2 (B), R39.1
unnamed: Q21.3 (C), R44.1
unnamed: Q22.2 (B), R38.1, R41.2
unnamed: Q23.2 (B), R40.1
unnamed: Q23.3 (C), R46.1
unnamed: Q24.2 (B), R42.1, R45.2
unnamed: Q25.2 (B), R43.1
unnamed: Q25.3 (C), R47.2
unnamed: Q26.2 (B), R47.1, R48.2
unnamed: R2.2, R3.1, U1.7 (DIS)
unnamed: R6.1, RV1.3
unnamed: R7.2, U3.1 (QB)
unnamed: R8.2, U3.5 (QF)
unnamed: R9.2, U4.1 (QB)
unnamed: R10.2, U5.2 (QC)
unnamed: R16.2, U4.2 (QC)
unnamed: R17.2, U3.6 (QG)
unnamed: R18.2, U4.3 (QD)
unnamed: R19.2, U5.3 (QD)
unnamed: R23.2, U3.2 (QC)
unnamed: R24.2, U3.7 (QH)
unnamed: R25.2, U5.15 (QA)
unnamed: R31.2, U3.3 (QD)
unnamed: R32.2, U3.15 (QA)
unnamed: R34.2, U5.4 (QE)
unnamed: R37.2, U5.1 (QB)
unnamed: R39.2, U3.4 (QE)
unnamed: R40.2, U4.15 (QA)
unnamed: R43.2, U5.5 (QF)
unnamed: U3.9 (~QH), U4.14 (SER)
unnamed: U4.9 (~QH), U5.14 (SER)
SERCLK: J1.7, U3.11 (SRCLK), U4.11 (SRCLK), U5.11 (SRCLK)
SERDATA: J1.3, U3.14 (SER)
SERDATAOUT: J1.9, U5.9 (~QH)
SERLATCH: J1.5, U3.12 (RCLK), U4.12 (RCLK), U5.12 (RCLK)

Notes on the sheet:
Nixie Scan Display by D. Marks KW4TI Creative Commons CC-BY-SA 4.0

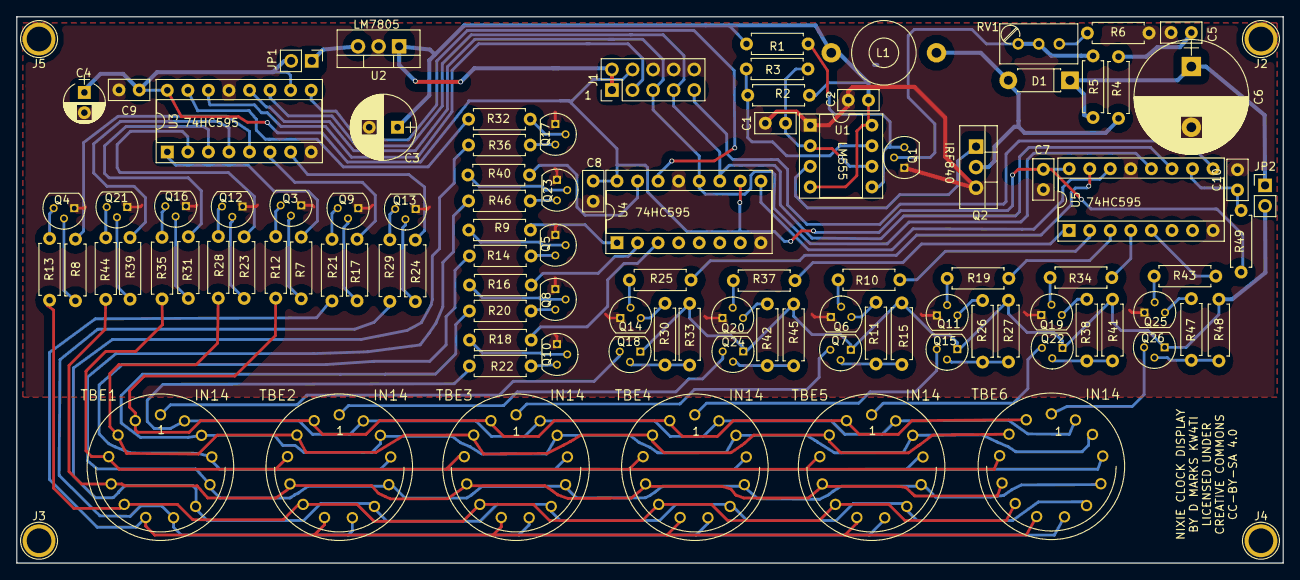
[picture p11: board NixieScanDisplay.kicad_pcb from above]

Board: 2 copper layers, 156.5 x 67.5 mm, 106 parts (0 on the bottom side), 99 nets.

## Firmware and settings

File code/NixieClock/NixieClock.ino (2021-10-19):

/*  NixieClock.ino */

/*
 * Copyright (c) 2020 Daniel Marks

This software is provided 'as-is', without any express or implied
warranty. In no event will the authors be held liable for any damages
arising from the use of this software.

Permission is granted to anyone to use this software for any purpose,
including commercial applications, and to alter it and redistribute it
freely, subject to the following restrictions:

1. The origin of this software must not be misrepresented; you must not
   claim that you wrote the original software. If you use this software
   in a product, an acknowledgment in the product documentation would be
   appreciated but is not required.
2. Altered source versions must be plainly marked as such, and must not be
   misrepresented as being the original software.
3. This notice may not be removed or altered from any source distribution.
 */

 #define DHT_SENSOR

#include <Arduino.h>
#include <SPI.h>
#include <Wire.h>
#include <EEPROM.h>
#include <DS3231.h>

#ifdef DHT_SENSOR
#include <DHT.h>
#endif

#define SERIAL_LATCH 10
#define SERIAL_DATA 11
#define SERIAL_DATAOUT 12
#define SERIAL_CLK 13
#define BUTTON1 14
#define BUTTON2 15
#define BUTTON3 16

#define ARDUINORX 1
#define ARDUINOTX 0

#define I2C_SDA 4
#define I2C_SCL 5

#define LED1 3
#define LED2 5
#define LED3 6

#define EEPROM_1224HR 0
#define EEPROM_TEMPCF 1

SPISettings spiA(4000000, MSBFIRST, SPI_MODE0);

#define NUM_DIGITS 6

//
// Display scanner control
//
// The display works by sweeping across the individual tubes, visiting each one
// briefly in round-robin fashion. During each visit, a tube's anode is powered
// while the cathode corresponding to the appropriate display elements (numeral
// and comma) are grounded. The microcontroller does this by shifting a bit
// string out to three cascaded shift registers whose outputs drive the the
// anodes and cathodes through high-voltage transistors. This is done in a
// four-phase refresh cycle driven asynchronously in the timer interrupt.
// 
// Bit string (Ax - anode X, Cx -- Cathode X, N -- not used)
//
// |        field 1        |        field 2        |        field 3        |
// |0 |1 |2 |3 |4 |5 |6 |7 |8 |9 |10|11|12|13|14|15|16|17|18|19|20|21|22|23|
// |      digit_code       |   number2/tick2_code  |   number1/tick1_code  |
// |A1|A2|A3|A4|A5|A6|N |N |C8|C9|C0|CB|N |N |N |N |CA|C7|C1|C2|C3|C4|C5|C6|
//

// Map between tube number (as index) and anode to activate in bit string field 1
const byte digit_code[] =   { 0x01, 0x02, 0x04, 0x08, 0x10, 0x20 };

// Map between digit (as index) and cathode to activate in bit string field 1
const byte number1_code[] = { 0x00, 0x04, 0x08, 0x10, 0x20, 0x40, 0x80, 0x01, 0x00, 0x00, 0x02, 0x00, 0x00 };

// Map between digit (as index) and cathode to activate in bit string field 2
const byte number2_code[] = { 0x04, 0x00, 0x00, 0x00, 0x00, 0x00, 0x00, 0x00, 0x01, 0x02, 0x00, 0x08, 0x00 };

// Map between control value (as index) and comma cathode in bit string field 1
const byte ticks1_code[] = { 0x00, 0x00, 0x02, 0x02 };

// Map between control value (as index) and comma cathode in bit string field 2
const byte ticks2_code[] = { 0x00, 0x08, 0x00, 0x08 };

// NOTE: Comma control codes:
//   0 - No commas lit
//   1 - TODO: (left?) comma lit
//   2 - TODO: (right?) comma lit
//   3 - Both commas lit

//
// Display states and configuration
//

volatile byte digits[NUM_DIGITS]; // Current values of each display digit
volatile byte ticks[NUM_DIGITS];  // Current comma states for each display digit
byte displayrefreshcycles;        // Current refresh phase in display refresh cycle
byte current_digit;               // Which display digit is being refreshed
byte hour12;                      // 0 => 24 hour display, !0 => 12 hour display
byte tempcf;                      // 0 => Celcius, !0 => Fahrenheit

//
// Devices
//

DS3231 Clock; // Real-time clock interface

#ifdef DHT_SENSOR
DHT DHTSensor(4, DHT22, 1); // Humidity/temperature sensor interface
#endif

//
// Push button support
//

#define NUM_BUTTONS 3

// Button GPIO assignments
const byte buttonPin[NUM_BUTTONS] = {BUTTON1, BUTTON2, BUTTON3};

// How many read cycles each button remained in current state; for debouncing
static byte constStateButton[NUM_BUTTONS];

// Current debounced state of each button
volatile byte curStateButton[NUM_BUTTONS];

// True for each button when debounced state shows button is depressed. This
// acts like a latch so that button push is detected even after user stops
// pushing
volatile bool pushedButton[NUM_BUTTONS];

// Return true iff the button is depressed (LOW value)
bool isButtonDown(byte b)
{
  return !curStateButton[b];
}

// Wait until a button is no longer depressed by the user
void waitButtonUp(byte b)
{
  // Buttons are active-low
  while (curStateButton[b] == LOW);
  pushedButton[b] = false;
}

// Return true when a button has been pushed
bool getPushedButton(byte b)
{
  if (pushedButton[b])
  {
    // Reset the latch remembering the button was pushed
    pushedButton[b] = false;
    return true;
  }

  return false;
}

// Sample current button values and update debounced states
void debounce_buttons(void)
{
  for (byte b = 0; b < NUM_BUTTONS; b++)
  {
    // Sample present button value
    byte state = digitalRead(buttonPin[b]);

    // If state value differs from the current debounced state...
    if (curStateButton[b] != state)
    {
      // a new debounced state is reached after 50 consistent read cycles
      if ((++constStateButton[b]) >= 50)
      {
        curStateButton[b] = state;

        // If the new state is LOW, the button is depressed (active-low)
        if (state == LOW) pushedButton[b] = true;

        constStateButton[b] = 0;
      }
    }

    // If same as current debounced state, restart debounce counter
    else
      constStateButton[b] = 0;
  }
}

// Update nixie tube LED illumination states
void write_led_state(byte d1, byte d2, byte d3)
{
  analogWrite(LED1,d1);
  analogWrite(LED2,d2);
  analogWrite(LED3,d3);
}

// Interrupt on timer: Update display and button press states
ISR(TIMER1_COMPA_vect)
{
  // Prepare to write to display- shifting digit lead codes to scan display shift registers
  SPI.beginTransaction(spiA);

  // 4 display refresh cycles per tube visit: 1-3: light the tube cathodes; 0: "rest" period
  if (displayrefreshcycles > 0)
  {
    displayrefreshcycles--;

    // Shift out activation bit string to tube control shift registers
    //
    // Bit string field 1
    SPI.transfer(digit_code[current_digit]);
    
    // Bit string field 2
    SPI.transfer(number2_code[digits[current_digit]] | ticks2_code[ticks[current_digit]]);

    // Bit string field 3
    SPI.transfer(number1_code[digits[current_digit]] | ticks1_code[ticks[current_digit]]);
  }
  else
  {
    displayrefreshcycles = 4;

    // Shut off the tube
    SPI.transfer(0);
    SPI.transfer(0);
    SPI.transfer(0);

    // Visit the next tube next cycle
    if ((++current_digit) >= NUM_DIGITS)
      current_digit = 0;
  }

  SPI.endTransaction();

  digitalWrite(SERIAL_LATCH, LOW);  // Low transition to set up for committing to display

  debounce_buttons();               // Update button press states; done here to give time
                                    // for serial latch signal to be effective

  digitalWrite(SERIAL_LATCH, HIGH); // Commit output to display
}

void setup() {
  // Initialize communication libraries, inputs, and outputs
  Serial.begin(9600);
  Wire.begin();
  current_digit = 0;
  pinMode(SERIAL_LATCH, OUTPUT);
  pinMode(LED1, OUTPUT);
  digitalWrite(LED1, LOW);
  pinMode(LED2, OUTPUT);
  digitalWrite(LED2, LOW);
  pinMode(LED3, OUTPUT);
  digitalWrite(LED3, LOW);
  pinMode(BUTTON1, INPUT);
  pinMode(BUTTON2, INPUT);
  pinMode(BUTTON3, INPUT);
  SPI.begin();

  // Set up MCU feature/mode registers
  noInterrupts();           // disable all interrupts
  TCCR1A = 0;
  TCCR1B = 0;
  TCNT1  = 0;
  OCR1A = 16;               // compare match register 16MHz/256/2Hz
  TCCR1B |= (1 << WGM12);   // CTC mode
  TCCR1B |= ((1 << CS11) | (1 << CS10));    // 256 prescaler
  TIMSK1 |= (1 << OCIE1A);  // enable timer compare interrupt
  interrupts();             // enable all interrupts

  Clock.setClockMode(false); // Set up real-time clock device

  // Fetch time and temperature display settings from EEPROM
  hour12 = (EEPROM.read(EEPROM_1224HR) == 1) ? 1 : 0;
  tempcf = (EEPROM.read(EEPROM_TEMPCF) == 1) ? 1 : 0;

#ifdef DHT_SENSOR
  DHTSensor.begin(); // Set up temp/humidity sensor device
#endif
}

// Set the current number shown by a particular pair of tubes
void display_1_number(byte ind, byte b)
{
  digits[ind] = b / 10;
  digits[ind + 1] = b % 10;
}

// Update the numbers shown by all three pairs of tubes
void display_three_numbers(byte n1, byte n2, byte n3)
{
  display_1_number(0, n1);
  display_1_number(2, n2);
  display_1_number(4, n3);
}

// Update the display numbers to be the current time
void display_current_time(void)
{
  bool h12, PM;
  byte nowHour = Clock.getHour(h12, PM);

  if (hour12)
  {
    if ((nowHour >= 12) && (nowHour <= 23)) ticks[0] = ticks[1] = 1;
    if (nowHour > 12) nowHour -= 12;
    if (nowHour == 0) nowHour = 12;
  }

  display_three_numbers(nowHour, Clock.getMinute(), Clock.getSecond());
}

// Update the display numbers to be the current datte
void display_current_date(void)
{
  bool Century;
  display_three_numbers(Clock.getYear(), Clock.getMonth(Century), Clock.getDate());
}

// Initialize each byte in a byte array to the same given value
void set_digs(byte *v, byte val)
{
  for (byte i = 0; i < NUM_DIGITS; i++) v[i] = val;
}

// Reset the display digits to invisible
void clear_display(void)
{
  // The number 12 maps to the activating none of the tube cathodes
  set_digs(digits, 12);
}

// Reset both commas for each digit to inivisible
void clear_ticks(void)
{
  set_digs(ticks, 0);
}

// Set both commas for each digit to visible
void all_ticks(void)
{
  set_digs(ticks, 3);
}

// Collect numeric user input ndig digits wide in a particular position on the display
// given an initial value and input range. NOTE: Timer interrupts are still enabled so
// that the display continues to update with digit/comma changes.
unsigned short getNewNumber(unsigned short n, byte dig, byte ndig, unsigned short minval, unsigned short maxval)
{
  clear_ticks();

  // Run a loop until the user is done (by pushing button 0)
  for (;;)
  {
    // Render the current value across the selected set of display tubes
    //
    unsigned short v = n;  // Copy current value for modification in loop below

    // Update each display digit with current value's digit in its decimal position 
    for (byte i = ndig; i > 0;)
    {
      i--;
      digits[dig + i] = v % 10;
      ticks[dig + i] = 3;
      v = v / 10;
    }

    // If button 2 is pushed, decrement the current value (wrapping around)
    if (getPushedButton(2))
    {
      if (n > minval) n--;
      else n = maxval;
    }

    // If button 1 is pushed, increment the current value (wrapping around)
    else if (getPushedButton(1))
    {
      if (n < maxval) n++;
      else n = minval;
    }

    // If button 0 is pushed, commit the current value
    else if (getPushedButton(0))
      break;
  }

  return n;
}

// Collect user input to set the clock and calendar
void set_time_and_date(void)
{
  bool h12, PM, Century;

  clear_display();
  delay(500);

  // First collect a number indicating 24-hour (0) or 12-hour (1) display
  hour12 = getNewNumber(hour12, 0, 1, 0, 1);
  EEPROM.write(EEPROM_1224HR, hour12); // Commit configuration to EEPROM

#ifdef DHT_SENSOR
  // Next collect a number indicating Celcius (0) or Fahrenheit (1) display
  clear_display();
  tempcf = getNewNumber(tempcf, 1, 2, 0, 1);
  EEPROM.write(EEPROM_TEMPCF, tempcf);
#endif

  // Show the current calendar (YYMMDD) and collect user changes
  display_three_numbers(Clock.getYear(), Clock.getMonth(Century), Clock.getDate());
  byte newYear = getNewNumber(Clock.getYear(), 0, 2, 0, 99);
  byte newMonth = getNewNumber(Clock.getMonth(Century), 2, 2, 1, 12);
  byte newDate = getNewNumber(Clock.getDate(), 4, 2, 1, 31);

  // Show the current time (HHMMSS) and collect user changtes
  display_current_time();
  byte newHour = Clock.getHour(h12, PM);
  newHour = getNewNumber(newHour, 0, 2, 0, 23);
  byte newMinute = getNewNumber(Clock.getMinute(), 2, 2, 0, 59);
  byte newSecond = getNewNumber(Clock.getSecond(), 4, 2, 0, 59);

  // Update the real-time clock device with new values
  Clock.setYear(newYear);
  Clock.setMonth(newMonth);
  Clock.setDate(newDate);
  Clock.setHour(newHour);
  Clock.setMinute(newMinute);
  Clock.setSecond(newSecond);

  // Affirm operation to user by showing all comma for a moment 
  all_ticks();
  delay(1000);
}

// Sweep through all the IN-14 nixie tube cathodes (display elements)
void cathode_condition()
{
  clear_ticks();

  // For each element (number and comma) individually
  for (byte i = 0; i < 12; i++)
  {
    // Set the element "hot"
    set_digs(digits, i);

    // Hold it that way for a while or until a signal from the user
    for (byte j = 0; j < 240; j++)
    {
      delay(250);
      if (getPushedButton(0)) break;  // button 0 -> go to next cathode
      if (getPushedButton(2)) return; // button 2 -> abort conditioning
    }
  }
}

#ifdef DHT_SENSOR
// Show the temperature and humidity
void display_dht(void)
{
  // Read the humidity/temperature values
  //
  // Reading temperature or humidity takes about 250 milliseconds!
  // Sensor readings may also be up to 2 seconds 'old' (its a very slow sensor)
  float h = DHTSensor.readHumidity();
  float f = DHTSensor.readTemperature(tempcf ? true : false);

  // Update each digit directly to the appropriate decimal value
  digits[0] = ((byte)f)/10;
  digits[1] = ((byte)f)%10;
  digits[2] = ((byte)(f*10.0f))%10;
  ticks[1] = 1;
  digits[3] = 12;
  digits[4] = ((byte)h)/10;
  digits[5] = ((byte)h)%10;
}
#endif

byte mainlooptick; // Current "time tick" in main loop display rotation cycle
byte programtick;  // "Time tick" counter for activating time and date set
byte cathodetick;  // "Time tick" counter for activating cathode conditioning

// Define the length of the display rotation between calendar, DHT, and time
#ifdef DHT_SENSOR
#define TICK_CENTRAL_LOOP 297
#else
#define TICK_CENTRAL_LOOP 247
#endif

void loop() {
  delay(100); // Define the width of a "time tick"

  // Reset display rotation after it reaches the end
  if ((++mainlooptick) > TICK_CENTRAL_LOOP) mainlooptick = 0;

  // Show current time during first part of display rotation
  if (mainlooptick < 150)
  {
    clear_ticks();
    write_led_state(0,0,255);
    display_current_time();
  }

#ifdef DHT_SENSOR
  // Show temp and humidity during second part of display rotation
  else if (mainlooptick < 237)
  {
    clear_ticks();
    write_led_state(0,255,0);
    display_dht();
  }
#endif

  // Show time and date during third part of display rotation
  else
  {
    clear_ticks();
    write_led_state(255,0,0);
    display_current_date();
    ticks[0] = ticks[2] = ticks[4] = 2;
    ticks[1] = ticks[3] = ticks[5] = 1;
  }

  // If the user is holding down button 2
  if (isButtonDown(2))
  {
    write_led_state(0,0,0); // Affirm by turning off the LEDs

    // If they hold it down for 20 ticks, set time and date
    if ((++programtick) >= 20)
    {
      programtick = 0;
      waitButtonUp(2);
      set_time_and_date();
    }
  }
  else
    // If the user isn't holding it down or lets go, reset counter
    programtick = 0;

  // If the user is holding down button 1
  if (isButtonDown(1))
  {
    write_led_state(0,0,0); // Affirm by turning off the LEDs

    // If they hold it down for 20 ticks, run the cathode conditioner
    if ((++cathodetick) >= 20)
    {
      cathodetick = 0;
      waitButtonUp(1);
      cathode_condition();
    }
  }
  else
    // If the user isn't holding it down or lets go, reset counter
    cathodetick = 0;
}

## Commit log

2019-12-31 Added a scanning PCB, much smaller
    [NixieClock.kicad_pcb, NixieClock.sch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]
2020-01-02 First commit of the Nixie Controller
    [NixieClock.kicad_pcb, NixieClock.sch, NixieTubes.sch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]
2020-01-03 Placed connectors to make boards stackable
    [NixieController.kicad_pcb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]
2020-03-02 First usable version of Nixie Tube Clock
    [NixieController-B.Cu.gbr, NixieController-B.Mask.gbr, NixieController-B.SilkS.gbr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]
2020-03-27 Added speaker output
    [NixieController-B.Cu.gbr, NixieController-B.Mask.gbr, NixieController-B.SilkS.gbr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]
2020-06-15 Changed connector between boards to 10 pin IDC, added Bill of Materials
    [NixieController-BOM.ods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]
2020-10-23 Added capacitors to buttons to filter noise
    [NixieController-B.Cu.gbr, NixieController-B.Mask.gbr, NixieController-B.SilkS.gbr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]
2021-09-26 Add nixie tube lead alignment tool
    [alignment-tool.stl, nixie-tube-lead-aligner.FCStd]
2021-09-26 Fixed slight error in schematic
    [NixieController.sch]
2021-09-30 Add simple clock enclosure CAD files
    [clock-enclosure-case-bottom.stl, clock-enclosure-top-wall.stl, clock-enclosure.FCStd]
2021-10-01 Improved enclosure
    [clock-enclosure-top-wall.stl, clock-enclosure.FCStd]
